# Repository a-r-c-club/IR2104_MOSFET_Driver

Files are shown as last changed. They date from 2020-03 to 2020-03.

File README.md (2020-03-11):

# Motor Driver
This repository contains all designs for motor driver designs made at VIIT Robotics.
## Design 1 : Comparator Design
This design contains a comparator and a totempole transistor configuration to drive paired N-channel and P-channel MOSFETs without bootstrap capacitors. The file names containing "mosfetdrivercomparator" are the files related to this design. 
## Design 2 : Bootstrap Capacitor Design
This design contains a gate driver IC named IR2104 which drives all N-channel MOSFETs in the H-bridge using a bootstrap capacitor. The file names containing "mosfet driver" are the files related to this design. Even all the Gerber and SVG files are related to this design. It is designed to be manufactured on industrial grades.

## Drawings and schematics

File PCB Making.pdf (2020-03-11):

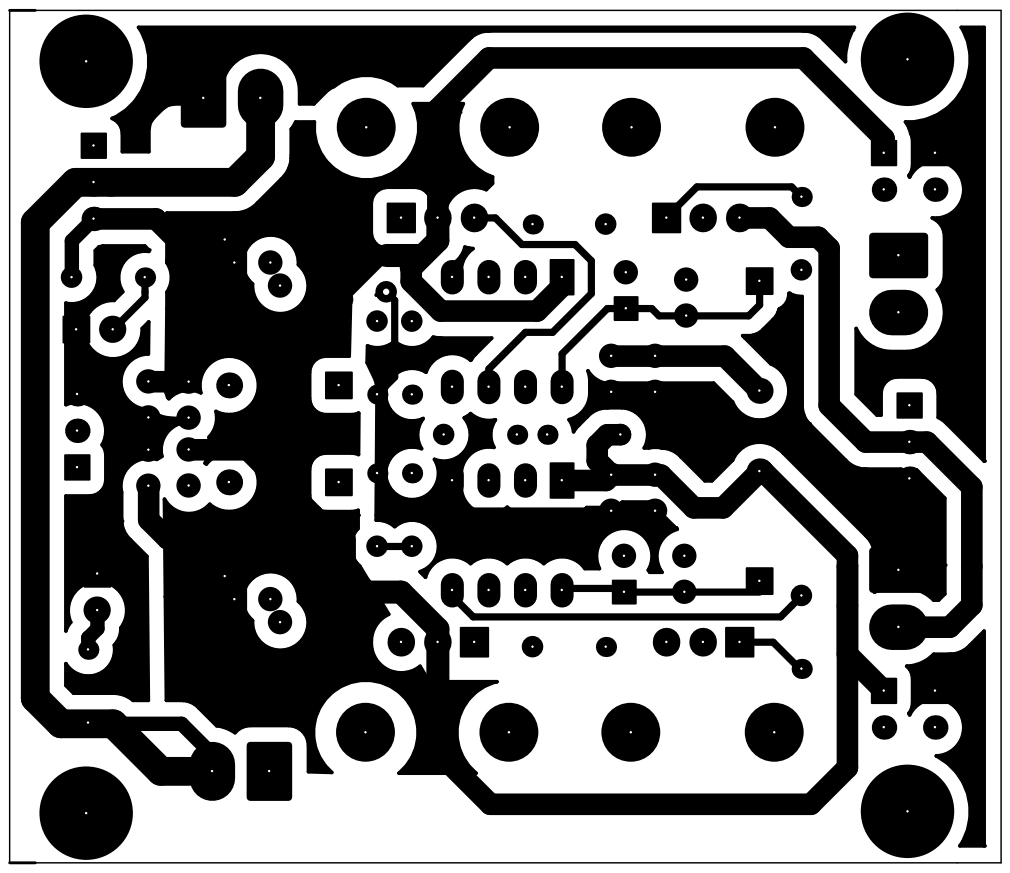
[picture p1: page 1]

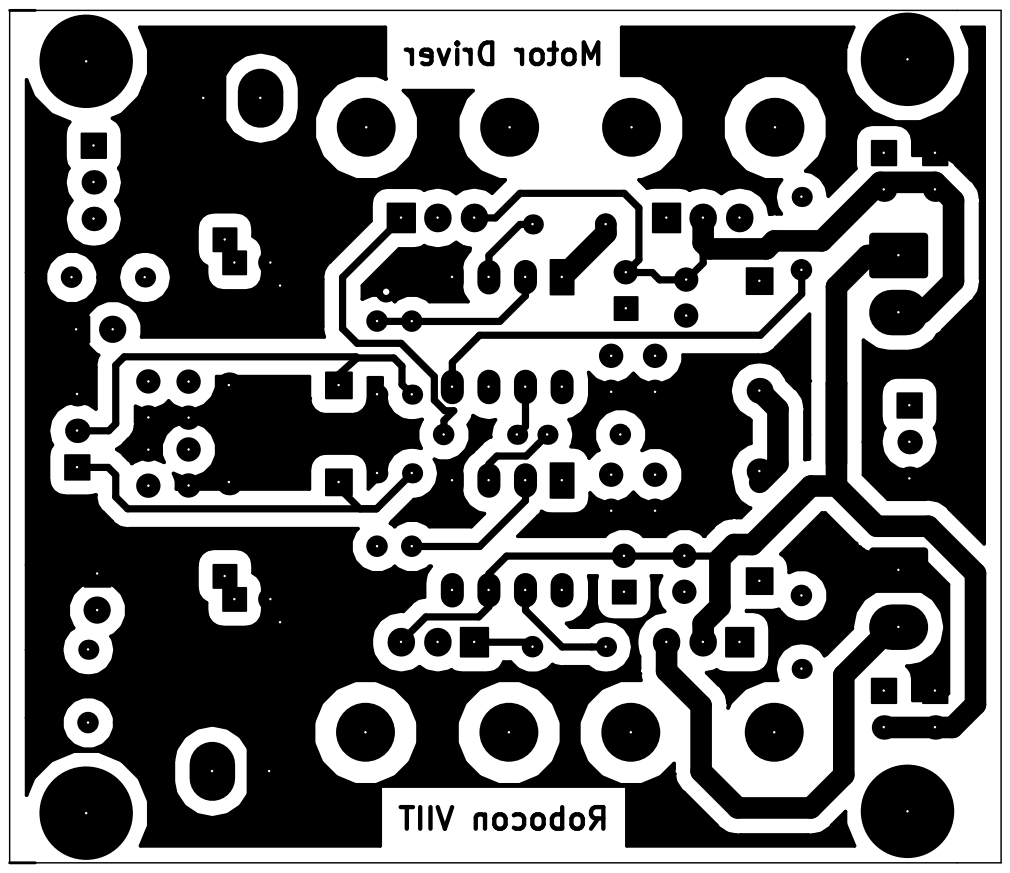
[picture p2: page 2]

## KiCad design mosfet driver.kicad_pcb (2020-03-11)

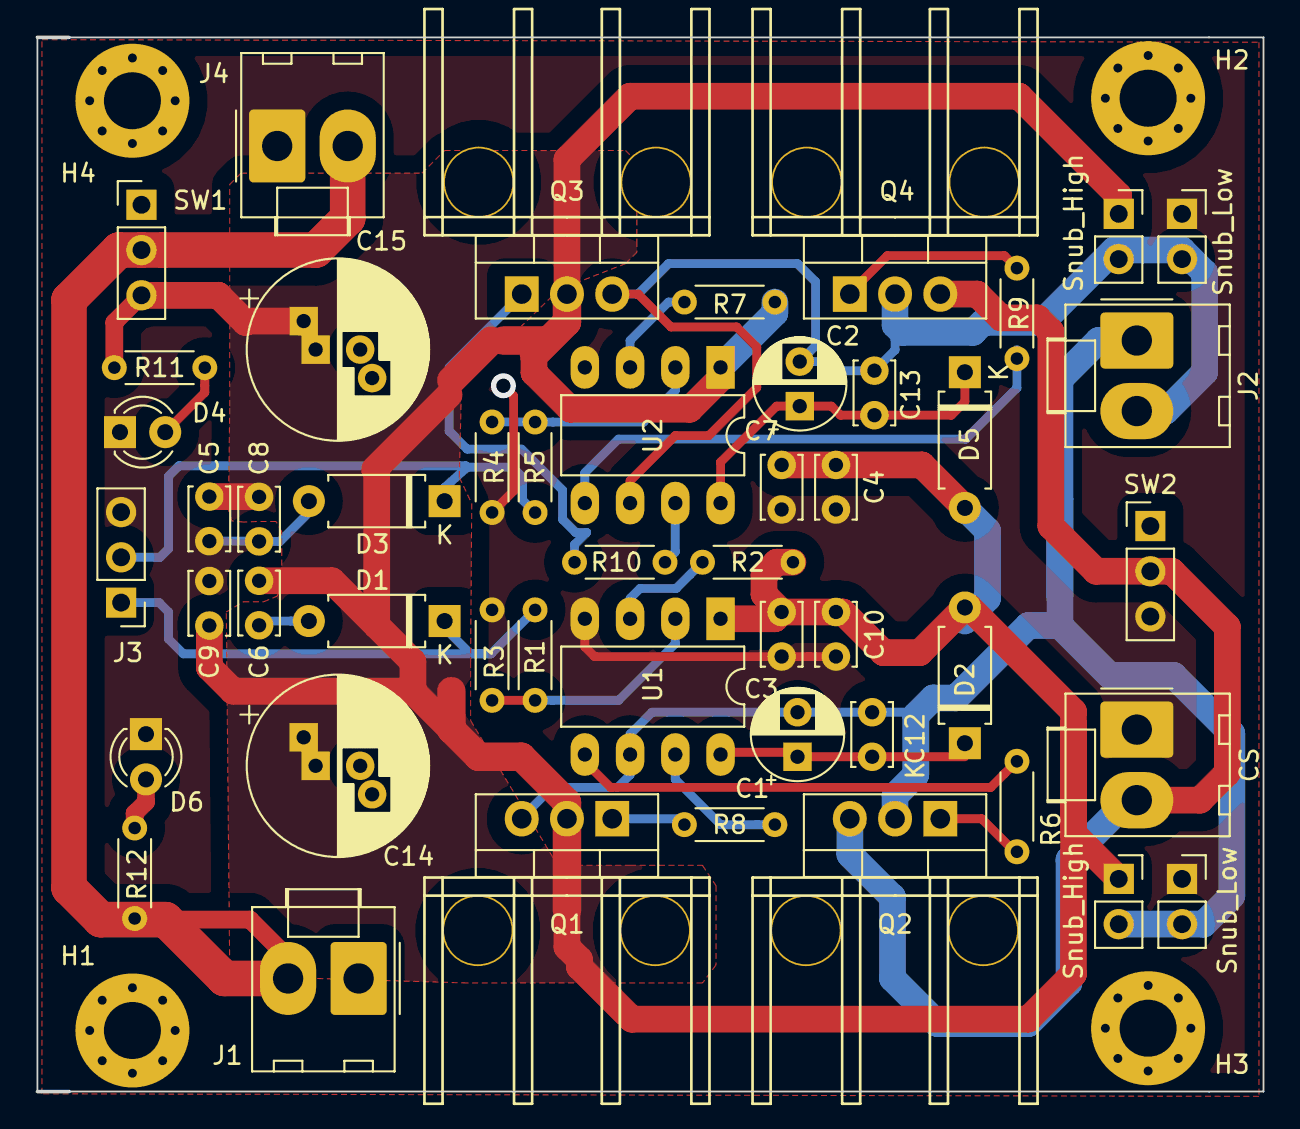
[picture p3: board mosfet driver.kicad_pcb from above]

Board: 2 copper layers, 68.8 x 59.2 mm, 53 parts (0 on the bottom side), 23 nets.

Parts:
C1, C2: BTSTRP; CP_Radial_D5.0mm_P2.50mm
C3, C4, C5, C6, C12, C13: 0.1uF; C_Disc_D3.4mm_W2.1mm_P2.50mm
C7, C8, C9, C10: 1uF; C_Disc_D3.4mm_W2.1mm_P2.50mm
C14, C15: 270uF/35V; CP_Radial_D10.0mm_P2.50mm_P5.00mm
CS: Molex_KK-396_A-41791-0002_1x02_P3.96mm_Vertical
D1, D3: 5.1 Zener; D_A-405_P7.62mm_Horizontal
D2, D5: 1N4148; D_A-405_P7.62mm_Horizontal
D4, D6: LED; LED_D3.0mm
H1, H2, H3, H4: MountingHole; MountingHole_3.2mm_M3_Pad_Via
J1, J4: PWR_IN; Molex_KK-396_A-41791-0002_1x02_P3.96mm_Vertical
J2: Screw_Terminal_01x02; Molex_KK-396_A-41791-0002_1x02_P3.96mm_Vertical
J3: Conn_01x03_Male; PinHeader_1x03_P2.54mm_Vertical
Q1, Q2, Q3, Q4: IRF3205; heatsinknew
R1, R5: 1K; R_Axial_DIN0204_L3.6mm_D1.6mm_P5.08mm_Horizontal
R2, R7: 10K; R_Axial_DIN0204_L3.6mm_D1.6mm_P5.08mm_Horizontal
R3, R4, R6, R8, R9, R10: 10; R_Axial_DIN0204_L3.6mm_D1.6mm_P5.08mm_Horizontal
R11, R12: 1k; R_Axial_DIN0204_L3.6mm_D1.6mm_P5.08mm_Horizontal
SW1: SW_DIP_x01; PinHeader_1x03_P2.54mm_Vertical
SW2: PinHeader_1x03_P2.54mm_Vertical
Snub_High: PinSocket_1x02_P2.54mm_Vertical
Snub_High#2: PinSocket_1x02_P2.54mm_Vertical
Snub_Low: PinSocket_1x02_P2.54mm_Vertical
Snub_Low#2: PinSocket_1x02_P2.54mm_Vertical
U1, U2: IR2104; DIP-8_W7.62mm_LongPads

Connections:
/Power3: C1.2, C12.2, J2.1, Q1.3, Q2.2, Snub_High.2, Snub_Low.2, U1.6
/Power4: C2.2, C13.2, J2.2, Q3.3, Q4.2, Snub_High#2.2, Snub_Low#2.2, U2.6
/Signal: D1.1, J3.1, R1.2
/Signal2: D3.1, J3.2, R5.2
GND: C3.2, C4.2, C5.2, C6.2, C7.2, C8.2, C9.2, C10.2, C14.2, C15.2, CS.1, D1.2, D3.2, D4.1, D6.1, J1.1, J3.3, J4.1, R3.2, R4.2, SW2.3, Snub_Low.1, Snub_Low#2.1, U1.4, U2.4
unnamed: C1.1, C12.1, D2.1, U1.8
unnamed: C2.1, C13.1, D5.1, U2.8
unnamed: D4.2, R11.2
unnamed: D6.2, R12.2
unnamed: J1.2, J4.2, R12.1, SW1.2
unnamed: Q1.1, R8.1
unnamed: Q2.1, R6.2
unnamed: Q3.1, R10.1
unnamed: Q4.1, R9.2
unnamed: R1.1, R3.1, U1.2
unnamed: R2.2, U1.3
unnamed: R4.1, R5.1, U2.2
unnamed: R6.1, U1.5
unnamed: R7.2, U2.3
unnamed: R8.2, U1.7
unnamed: R9.1, U2.5
unnamed: R10.2, U2.7
VCC: C3.1, C4.1, C5.1, C6.1, C7.1, C8.1, C9.1, C10.1, C14.1, C15.1, D2.2, D5.2, Q1.2, Q3.2, R2.1, R7.1, R11.1, SW1.3, Snub_High.1, Snub_High#2.1, U1.1, U2.1

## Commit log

2019-10-25 Resistor issue fixed
    [IRF2104 Driver.kicad_pcb]
2020-03-11 Design for manufacturing double sided PCB
    This does not however contain any passive components which are needed for filtering input not output. This isn't final yet.
    [mosfet driver.dsn, mosfet driver.kicad_pcb, mosfet driver.sch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]
2020-03-11 Input and output filters added
    Changes suggested by Malhar implemented. Input and output filters added. Output for current sensor added. MOLEX connector outputs added. LED added. Switches added.
    [mosfet driver.sch]
2020-03-11 Current Sensor placement solved
    Switch for current sensor added for bypassing it whenever unnecessary. This board is also tailored for manufacturing in-house.
    [mosfet driver-B.CrtYd.gbr, mosfet driver-B.Cu.gbr, mosfet driver-B.Mask.gbr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]
2020-03-11 Discarded Old Design
    [IRF2104 Driver.kicad_pcb]
2020-03-11 Files in the wrong branch deleted
    [IRF2104 Driver.kicad_pcb]
2020-03-11 Old design removed from master
    [IRF2104 Driver.sch]
2020-03-11 Comparator Design (Modified by Sharwari)
    [mosfetdrivercomparator.kicad_pcb]
2020-03-11 Wrong file in the branch
    [mosfet driver-B.CrtYd.gbr]
2020-03-11 Manufacturing quality
    Finalised board. Bypass for current sensor added.
    [mosfet driver.dsn, mosfet driver.kicad_pcb, mosfet driver.sch]
2020-03-11 Gerber for industrial manufacturing
    [mosfet driver-B.CrtYd.gbr, mosfet driver-B.Cu.gbr, mosfet driver-B.Mask.gbr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]
